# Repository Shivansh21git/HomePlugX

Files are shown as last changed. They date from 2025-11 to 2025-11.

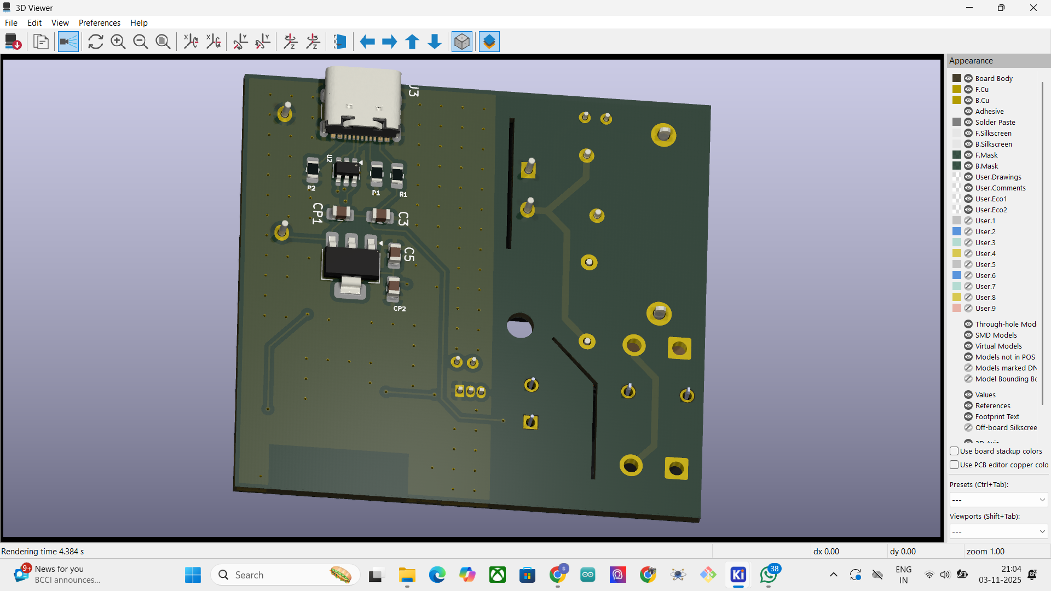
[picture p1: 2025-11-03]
3d/Screenshot (130).png

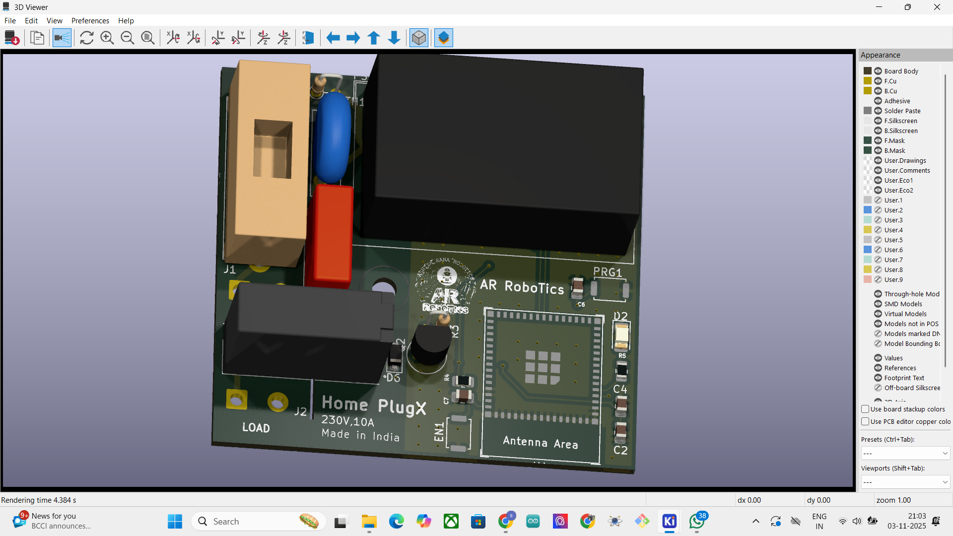
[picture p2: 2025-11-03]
3d/Screenshot (129).png

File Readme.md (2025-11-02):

# 🔌 HomePlugX

**HomePlugX** is a compact IoT smart plug built around the **ESP32** (or ESP32-S3) platform.  
It enables wireless control, timer, and scheduling of any 230 VAC appliance up to **10 A**, with built-in protection and energy monitoring capability.

---

## ⚙️ Features

- ✅ Wi-Fi control via ESP32 / ESP32-S3
- ⏱️ Timer and scheduling support (App-based)
- ⚡ Energy metering using HLW8012 / HLW8032
- 🔥 Relay control with transistor or MOSFET driver
- 🧰 Built-in surge and over-current protection
- 📱 Android app made using MIT App Inventor
- 💡 Compact, low-power, and safe for home use

---

## 🧩 Hardware Overview

| Section | Component | Function |
|---|---|---|
| **Power Input** | Fuse + MOV + NTC + X2 Cap | Surge & inrush protection |
| **AC-DC Conversion** | HLK-PM05 | 230 VAC → 5 VDC isolated |
| **Regulator** | SPX3819 / AMS1117 | 5 V → 3.3 V for ESP32 |
| **Relay** | HF46F (10 A) | Switches live line |
| **Driver** | 2N2222 / IRLML2502 | Relay drive transistor / MOSFET |
| **MCU** | ESP32-S3 Mini / ESP32-WROOM | Core controller with Wi-Fi + BT |
| **Energy Meter** | HLW8012 / HLW8032 | Measures current, voltage, power |
| **Enclosure** | Plastic housing | Insulated & compact plug body |

---

## 🔋 Electrical Ratings

| Parameter | Value |
|---|---|
| Input Voltage | 230 VAC ±10 % |
| Load Current | Up to 10 A (resistive) |
| Output Power | Up to 2.3 kW |
| Isolation | 3 kV (HLK-PM05) |
| Standby Power | < 1 W |

---

## 🧠 Software Features

- MQTT / HTTP communication  
- Local web control page  
- Countdown timer and real-time clock scheduling  
- OTA firmware update (optional)  
- Energy-usage reporting and overload cut-off  

---

## 🧰 Development Stack

- **Firmware:** Arduino IDE / ESP-IDF  
- **Mobile App:** MIT App Inventor  
- **PCB Design:** KiCad / EasyEDA  
- **Database / Visualization (optional):** InfluxDB + Grafana  
- **Version Control:** Git + GitHub  

---

## 🛠️ Getting Started

### 1. Hardware Setup
1. Assemble HLK-PM05, protection components, relay, and MCU as per schematic.  
2. Flash firmware using USB-to-UART converter.  
3. Power the board **only through isolation** during initial testing.

### 2. Firmware Flash
```bash
git clone https://github.com/yourusername/HomePlugX.git
cd HomePlugX
# open in Arduino IDE or ESP-IDF and upload

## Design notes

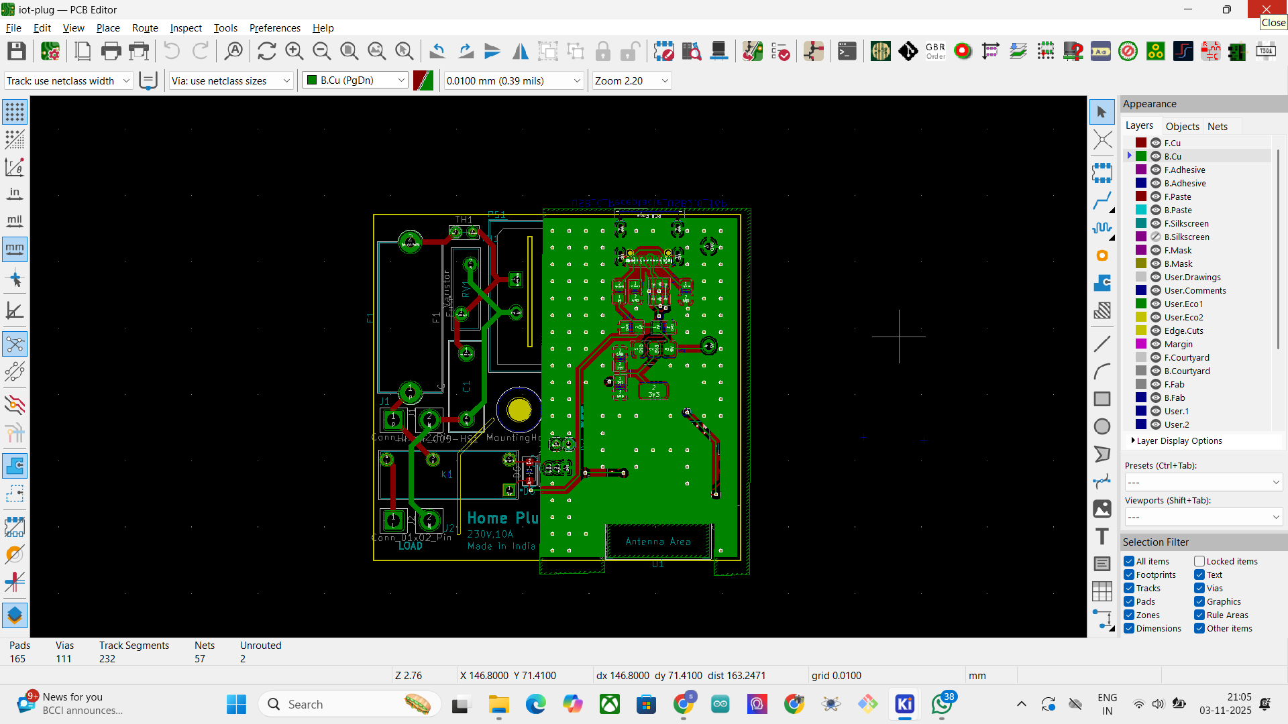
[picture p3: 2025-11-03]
3d/Screenshot (132).png

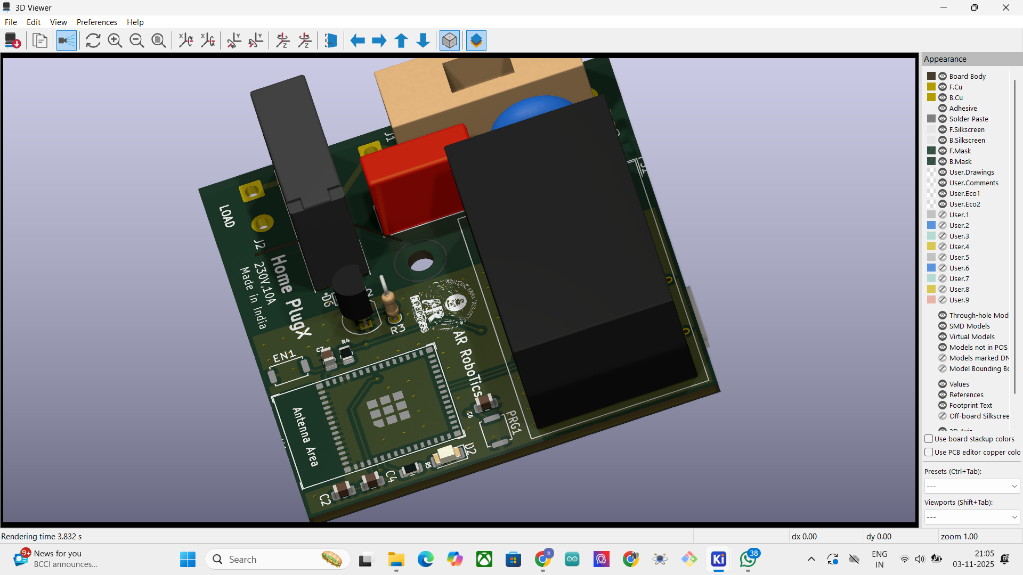
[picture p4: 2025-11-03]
3d/Screenshot (131).png

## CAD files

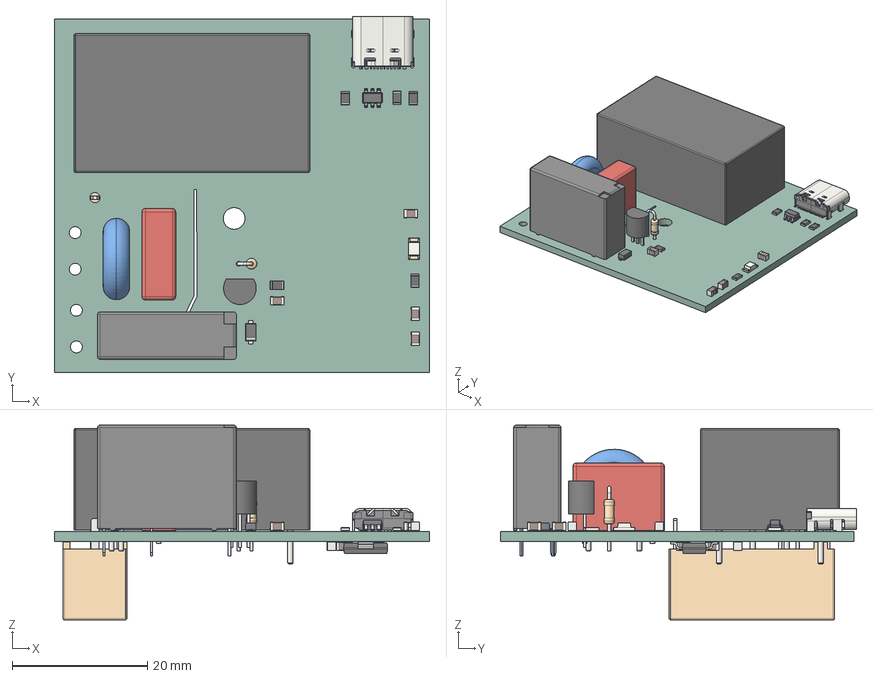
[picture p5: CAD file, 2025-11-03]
iot-plug.step
55.4 x 52.6 x 28.8 mm
R_Axial_DIN0204_L3.6mm_D1.6mm_P2.54mm_Vertical
R_0805_2012Metric x 5
C_0805_2012Metric x 8
D_SOD-123F
R_Axial_DIN0204_L3.6mm_D1.6mm_P1.90mm_Vertical
Converter_ACDC_Hi-Link_HLK-PMxx
C_Rect_L13.5mm_W5.0mm_P10.00mm_FKS3_FKP3_MKS4
HF46F_005-HS1
SOT-23-6
RV_Disc_D12mm_W3.9mm_P7.5mm
USB_C_Receptacle_GCT_USB4105-xx-A_16P_TopMnt_Horizontal
LED_1206_3216Metric
TO-92_Inline
Fuseholder_Cylinder-5x20mm_Stelvio-Kontek_PTF78_Horizontal_Open
SOT-223
iot-plug_PCB

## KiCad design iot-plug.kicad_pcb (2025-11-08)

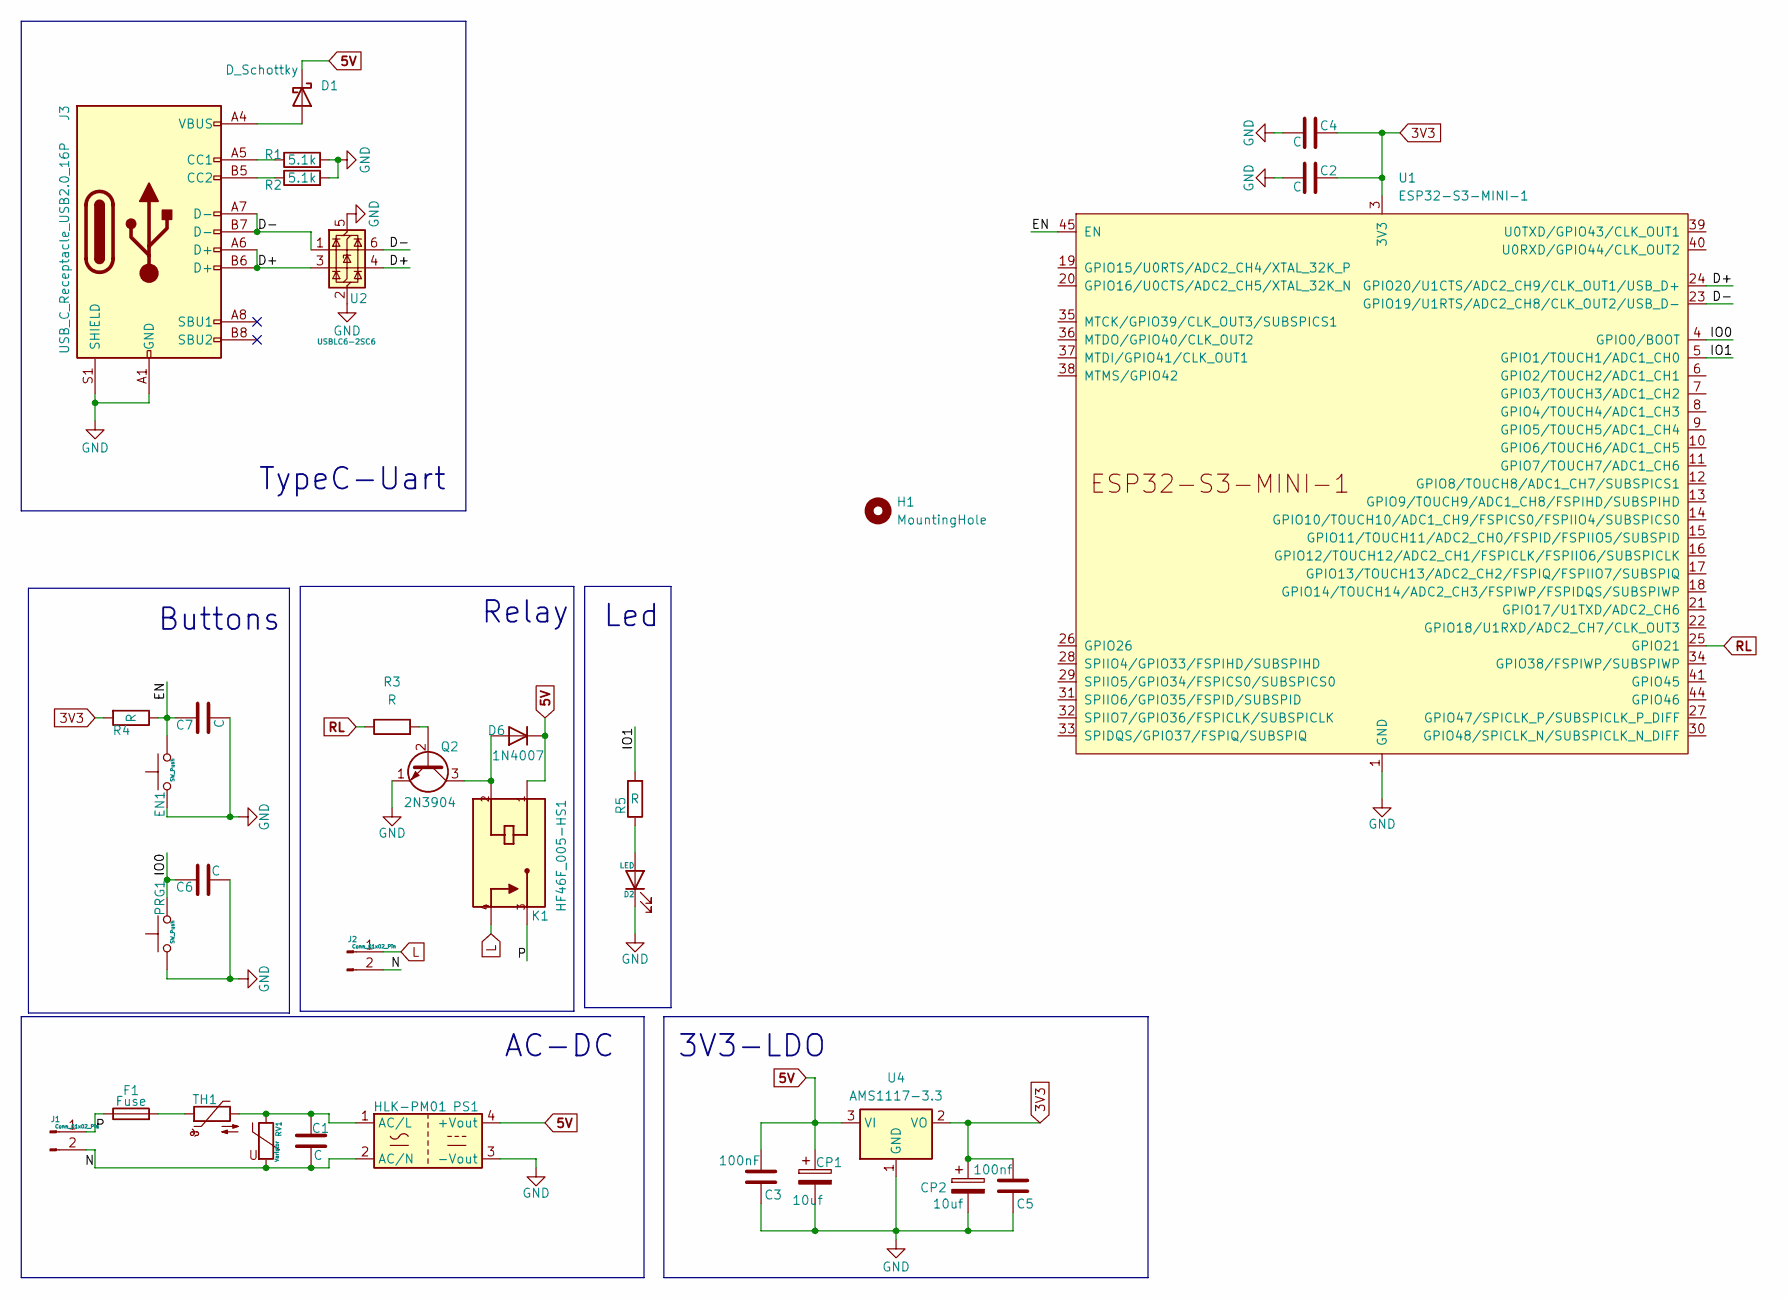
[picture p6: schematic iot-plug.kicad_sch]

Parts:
C1: C; C_Rect_L13.5mm_W5.0mm_P10.00mm_FKS3_FKP3_MKS4
C2, C4, C6, C7: C; C_0805_2012Metric
C3: 100nF; C_0805_2012Metric_Pad1.18x1.45mm_HandSolder
C5: 100nf; C_0805_2012Metric_Pad1.18x1.45mm_HandSolder
CP1, CP2: 10uf; C_0805_2012Metric_Pad1.18x1.45mm_HandSolder
D1: D_Schottky; R_0805_2012Metric_Pad1.20x1.40mm_HandSolder
D2: LED; LED_1206_3216Metric
D6: 1N4007; D_SOD-123F
EN1: SW_Push; SW_Push_SPST_NO_Alps_SKRK
F1: Fuse; Fuseholder_Cylinder-5x20mm_Stelvio-Kontek_PTF78_Horizontal_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
H1: MountingHole; MountingHole_3.2mm_M3
J1, J2: Conn_01x02_Pin; SolderWire-1sqmm_1x02_P5.4mm_D1.4mm_OD2.7mm
J3: USB_C_Receptacle_USB2.0_16P; USB_C_Receptacle_GCT_USB4105-xx-A_16P_TopMnt_Horizontal
K1: HF46F_005-HS1; RELAY_HF46F_005-HS1; PARTREV 1.00
PRG1: SW_Push; SW_Push_SPST_NO_Alps_SKRK
PS1: HLK-PM01; Converter_ACDC_Hi-Link_HLK-PMxx
Q2: 2N3904; TO-92_Inline
R1, R2: 5.1k; R_0805_2012Metric_Pad1.20x1.40mm_HandSolder
R3: R; R_Axial_DIN0204_L3.6mm_D1.6mm_P1.90mm_Vertical
R4, R5: R; R_0805_2012Metric
RV1: Varistor; RV_Disc_D12mm_W3.9mm_P7.5mm
TH1: Thermistor_NTC; R_Axial_DIN0204_L3.6mm_D1.6mm_P2.54mm_Vertical
U1: ESP32-S3-MINI-1
U2: USBLC6-2SC6; SOT-23-6
U4: AMS1117-3.3; SOT-223-3_TabPin2

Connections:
3V3: C2.1, C4.1, C5.2, CP2.1, R4.2, U1.3 (3V3), U4.2 (VO)
5V: C3.2, CP1.1, D1.1 (K), D6.1 (K), K1.1, PS1.4 (+Vout), U4.3 (VI)
/D+: J3.A6 (D+), J3.B6 (D+), U1.24 (GPIO20/U1CTS/ADC2_CH9/CLK_OUT1/USB_D+), U2.3 (I/O2), U2.4 (I/O2)
/D-: J3.A7 (D-), J3.B7 (D-), U1.23 (GPIO19/U1RTS/ADC2_CH8/CLK_OUT2/USB_D-), U2.1 (I/O1), U2.6 (I/O1)
/EN: C7.1, EN1.2, R4.1, U1.45 (EN)
/IO0: C6.1, PRG1.2, U1.4 (GPIO0/BOOT)
/IO1: R5.2, U1.5 (GPIO1/TOUCH1/ADC1_CH0)
/N: C1.2, J1.2, J2.2, PS1.2 (AC/N), RV1.2
/P: F1.1, J1.1, K1.3
GND: C2.2, C3.1, C4.2, C5.1, C6.2, C7.2, CP1.2, CP2.2, D2.1 (K), EN1.1, J3.A1 (GND), J3.A12 (GND), J3.B1 (GND), J3.B12 (GND), J3.S1 (SHIELD), PRG1.1, PS1.3 (-Vout), Q2.1 (E), R1.2, R2.2, U1.1 (GND), U1.2 (GND), U1.42 (GND), U1.43 (GND), U1.46 (GND), U1.47 (GND), U1.48 (GND), U1.49 (GND), U1.50 (GND), U1.51 (GND), U1.52 (GND), U1.53 (GND), U1.54 (GND), U1.55 (GND), U1.56 (GND), U1.57 (GND), U1.58 (GND), U1.59 (GND), U1.60 (GND), U1.61 (GND), U1.62 (GND), U1.63 (GND), U1.64 (GND), U1.65 (GND), U2.2 (GND), U2.5 (VBUS), U4.1 (GND)
L: J2.1, K1.4
unnamed: D1.2 (A), J3.A4 (VBUS), J3.A9 (VBUS), J3.B4 (VBUS), J3.B9 (VBUS)
unnamed: D2.2 (A), R5.1
unnamed: D6.2 (A), K1.2, Q2.3 (C)
unnamed: F1.2, TH1.1
unnamed: J3.A5 (CC1), R1.1
unnamed: J3.B5 (CC2), R2.1
unnamed: C1.1, PS1.1 (AC/L), RV1.1, TH1.2
unnamed: Q2.2 (B), R3.2
RL: R3.1, U1.25 (GPIO21)

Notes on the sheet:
3V3-LDO
TypeC-Uart
Relay
Buttons
AC-DC
Led

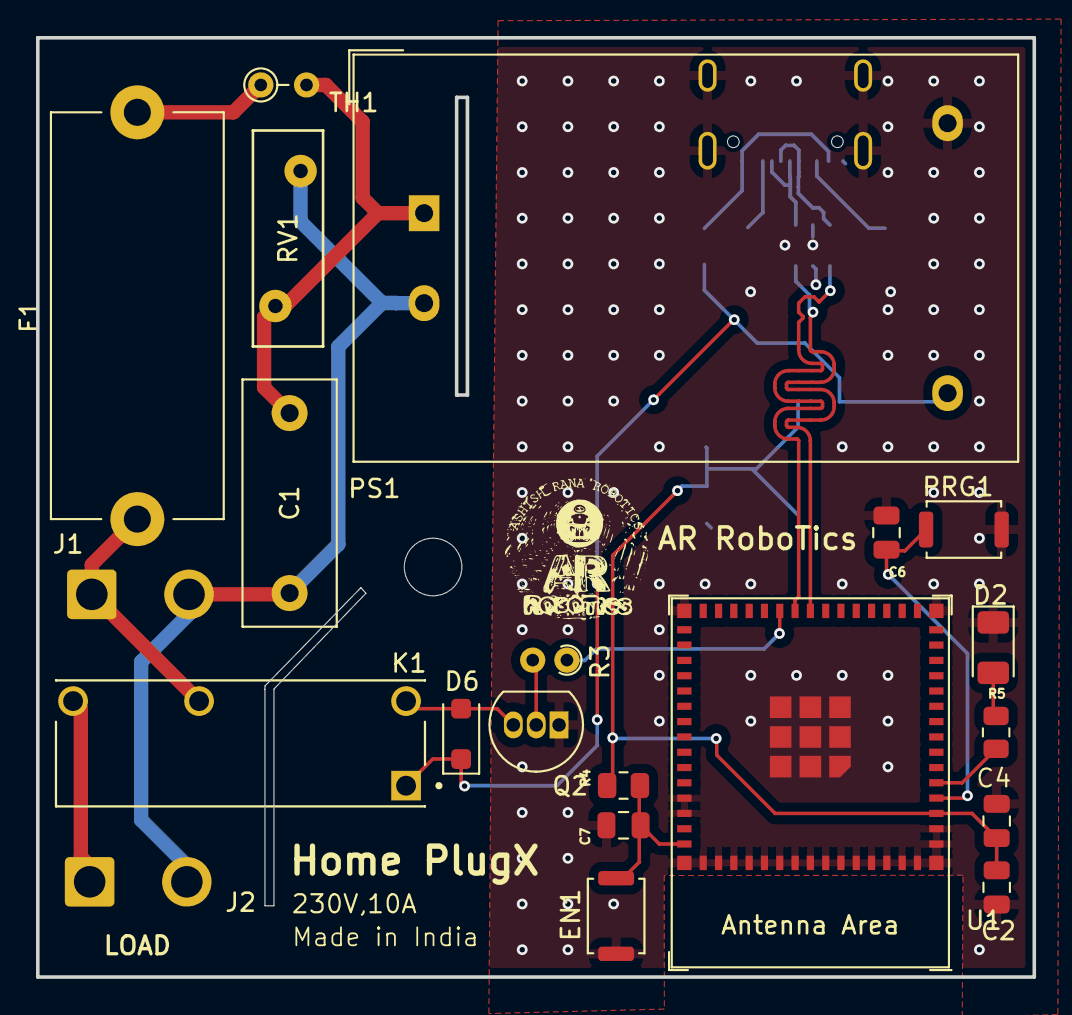
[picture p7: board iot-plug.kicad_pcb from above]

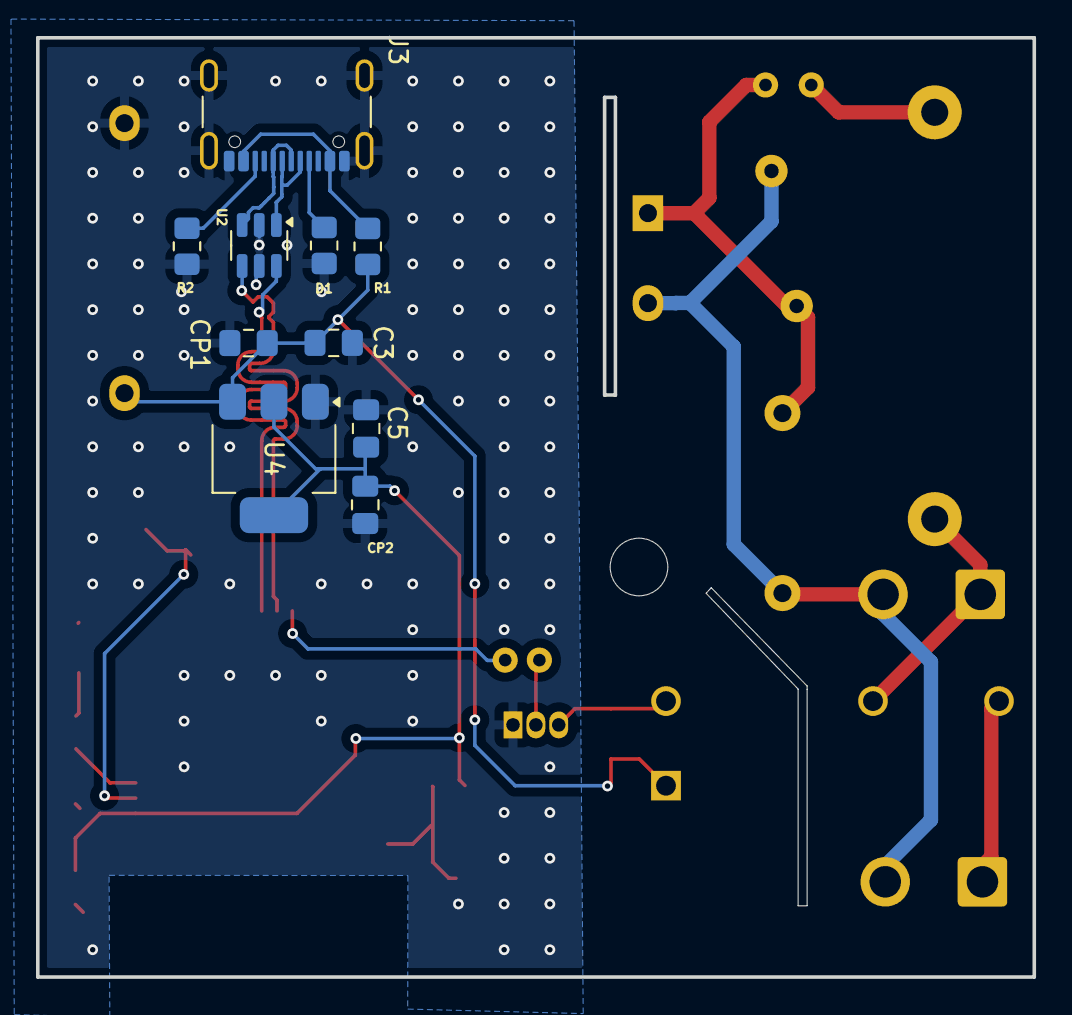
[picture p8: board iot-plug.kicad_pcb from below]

Board: 2 copper layers, 55.4 x 52.2 mm, 32 parts (10 on the bottom side), 20 nets.

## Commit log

2025-11-02 initial commit from coolPC
    [iot-plug.kicad_pcb, iot-plug.kicad_sch]
2025-11-02 from shivpc
    [iot-plug.kicad_pcb]
2025-11-03 layout updated
    [iot-plug.kicad_pcb, iot-plug.kicad_sch, iot-plug.step]
2025-11-03 logo added
    [iot-plug.kicad_pcb]
2025-11-05 updated tracks & nets
    [iot-plug.kicad_pcb, iot-plug.kicad_sch]
